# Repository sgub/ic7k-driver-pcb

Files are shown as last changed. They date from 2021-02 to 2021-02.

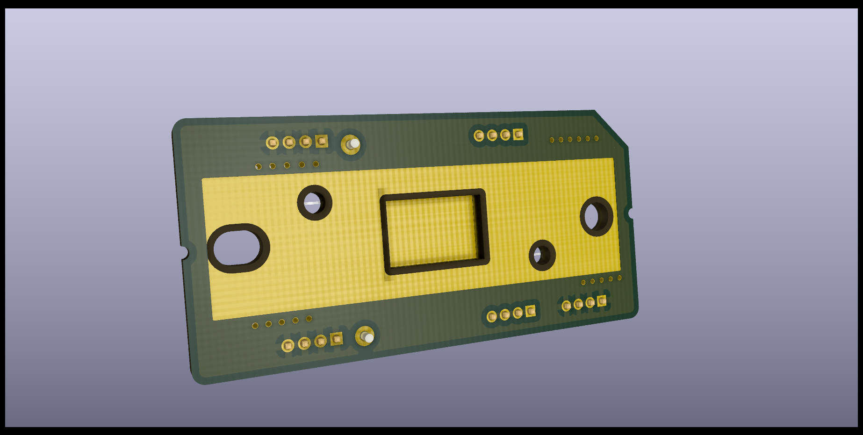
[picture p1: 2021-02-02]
ic7000_drive_bottom.png

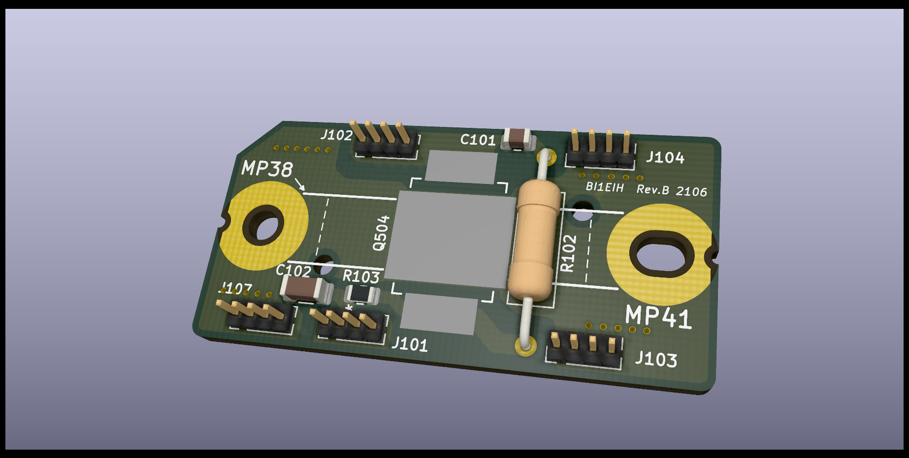
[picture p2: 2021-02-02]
ic7000_drive_front.png

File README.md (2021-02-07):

# Improved IC-7000 HF/VHF/UHF Transceiver driver stage PCB

## Features:
* Reduce pinheader spacing from 1.5mm to 1.27mm, for better availability of parts and easier mating with the PA board.
* Added resistor R103 in series with the gate of the MOSFET, to suppress self oscillication on certain conditions which could burn-off the driver module.

## BOM:
* Q504: ST Microelectronics PD55015-E 550MHz/15W MOSFET, PowerSO-10 Package, formed lead.
* R103: Choose a value by experiment from 1ohm (moderate damping) to 10ohm (~50% reduced final output power on UHF, but much safer), size 0805
* R102: 100ohm/1W, Axial_DIN0309_L9.0mm_D3.2mm_P15.24mm. Size is critical due to limited installation space.
* J107,J104,J103,J102,J101: PinHeader_1x04_P1.27mm_Vertical, 11mm total height.
* C102: 39pF/100V, Size 1206.
* C101: 10nF/50V, size 0805.

## Build notes:
* Prefered board material is FR4 double layer, 1.6mm thick.
* Apply enough solder between the underside of the MOSFET and the heatsink for effective heat conducting, avoid space, soldering/heating with proper tool. Refer STMicroelectronics AN1294 Application note for temperature limit and technique recommendation.

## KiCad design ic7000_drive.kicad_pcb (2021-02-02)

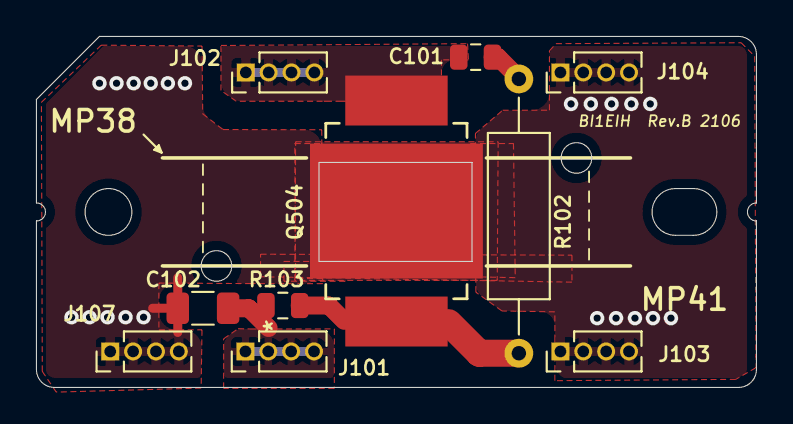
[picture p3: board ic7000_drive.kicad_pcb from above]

Board: 2 copper layers, 40.0 x 19.5 mm, 10 parts (0 on the bottom side), 5 nets.

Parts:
C101: 0.1µF; C_0805_2012Metric
C102: 39p; C_1206_3216Metric
J101, J102, J103, J104, J107: Conn_01x04; PinHeader_1x04_P1.27mm_Vertical
Q504: PD55015-E; PD55008-E
R102: 100R/1W; R_Axial_DIN0309_L9.0mm_D3.2mm_P15.24mm_Horizontal
R103: 100R*; R_0805_2012Metric

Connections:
GND: C102.2, J103.1, J103.2, J103.3, J103.4, J104.1, J104.2, J104.3, J104.4, J107.1, J107.2, J107.3, J107.4, Q504.EPAD
unnamed: C101.1, R102.2
unnamed: C101.2, J102.1, J102.2, J102.3, J102.4, Q504.2
unnamed: C102.1, J101.1, J101.2, J101.3, J101.4, R103.1
unnamed: Q504.1, R102.1, R103.2

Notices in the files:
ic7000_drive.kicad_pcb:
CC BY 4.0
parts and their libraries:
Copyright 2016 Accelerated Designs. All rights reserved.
